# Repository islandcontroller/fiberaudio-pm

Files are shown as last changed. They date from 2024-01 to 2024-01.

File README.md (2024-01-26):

# fiberaudio-pm 

  

A *Pmod&trade; Compatible* peripheral module featuring a pair of active optical audio transmitter/receivers.

<p align="center">
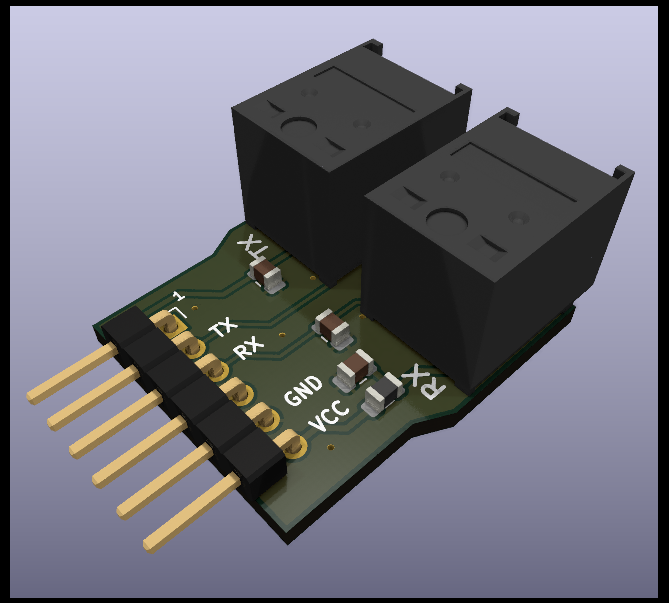
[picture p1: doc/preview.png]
Block schematic
  
</picture></p>

View [**Schematic**](doc/fiberaudio-pm.pdf) &#128196; or [**PCB Preview**](https://htmlpreview.github.io/?https://github.com/islandcontroller/fiberaudio-pm/blob/master/doc/ibom.html) &#127760;.

### Key features

* One pair of active optical audio transmitter/receiver modules (JIS F05, e.g. TOSLINK&trade;)
* One *Digilent Pmod&trade; Compatible* 1x6 pin header
    * Interface Type 1 (GPIO)
* Fully compliant with the [*Digilent Pmod&trade; Interface Specification*, Version 1.3.1](https://digilent.com/reference/_media/reference/pmod/pmod-interface-specification-1_3_1.pdf)

## Overview

The *Pmod&trade; Compatible* fiberaudio-pm peripheral module features a pair of active optical audio transmitter/receiver modules, commonly referred to as "optical S/PDIF". The module allows embedded developers to explore optical data transfer technologies using *Digilent Pmod&trade;* ecosystem components, such as FPGA development boards.

## Review Notes (`Rev.2`)

* CE marking requires compliance with [Directive 2015/863 (EU) amending Annex II to Directive 2011/65/EU](https://eur-lex.europa.eu/legal-content/EN/TXT/?uri=CELEX:32015L0863) (RoHS)
* WEEE marking not required if the board is classified as a 'component' according to [FAQ on Directive 2012/19/EU](https://ec.europa.eu/environment/pdf/waste/weee/faq.pdf) (WEEE)
  * Removed marking in `Rev.3`
* Heat-sinking effect of GND pad thermal spokes is excessive at 400µm width
  * Adjusted to 250µm in `Rev.4`
* "VCC" and "GND" silkscreen placed too close to connector `J1`. Stroke could be a bit wider for better readability.
  * Adjusted position and size in `Rev.4`

## Resources

* [Digilent Pmod&trade; License Agreement](https://digilent.com/reference/_media/pmod/pmod/pmod_license_agreement.pdf)
* Digilent Reference: [Programmable Logic](https://digilent.com/reference/programmable-logic/start)

## Licensing

If not stated otherwise within the specific file, the contents of this project are licensed under the CERN Open Hardware Licence Version 2 - Permissive. The full license text is provided in the [`LICENSE`](LICENSE) document.

    SPDX-License-Identifier: CERN-OHL-P-2.0

This licensing model is compliant with the [Open Source Hardware Definition 1.0](https://www.oshwa.org/definition/).

## Legal Notice

"Digilent" is a registered trademark of *Digilent, Inc*. All other trademarks and registered trademarks mentioned herein are property of their respective owners.

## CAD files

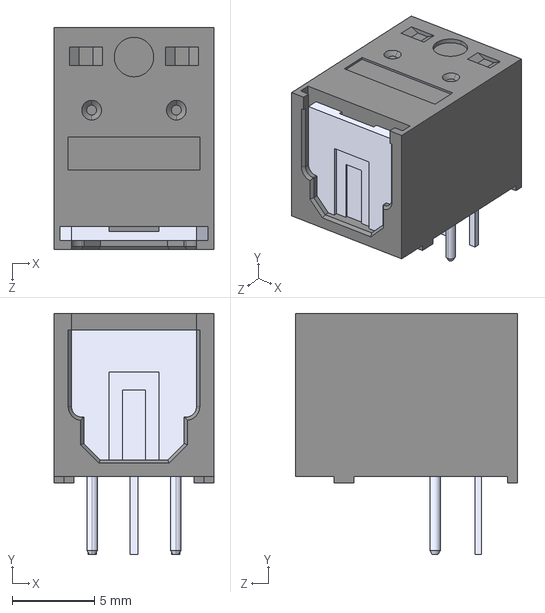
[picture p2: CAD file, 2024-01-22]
doc/everlight_t10w.step
9.70 x 14.7 x 13.5 mm

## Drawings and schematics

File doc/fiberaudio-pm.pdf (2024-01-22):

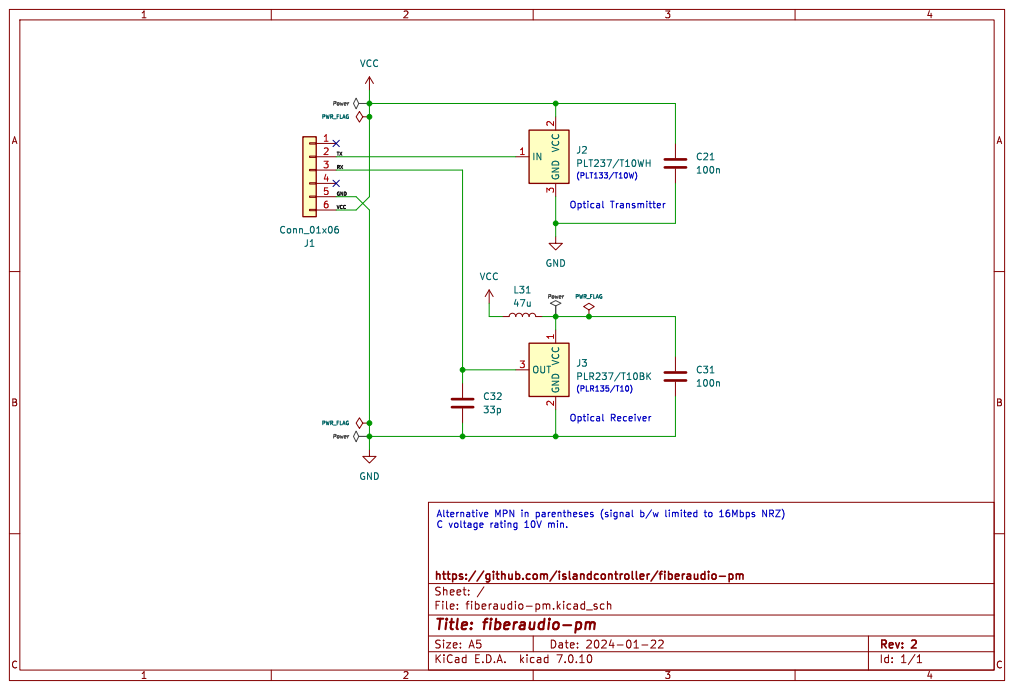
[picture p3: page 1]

File: fiberaudio-pm.kicad_sch Sheet: / https://github.com/islandcontroller/fiberaudio-pm

Id: 1/1 Title: fiberaudio-pm

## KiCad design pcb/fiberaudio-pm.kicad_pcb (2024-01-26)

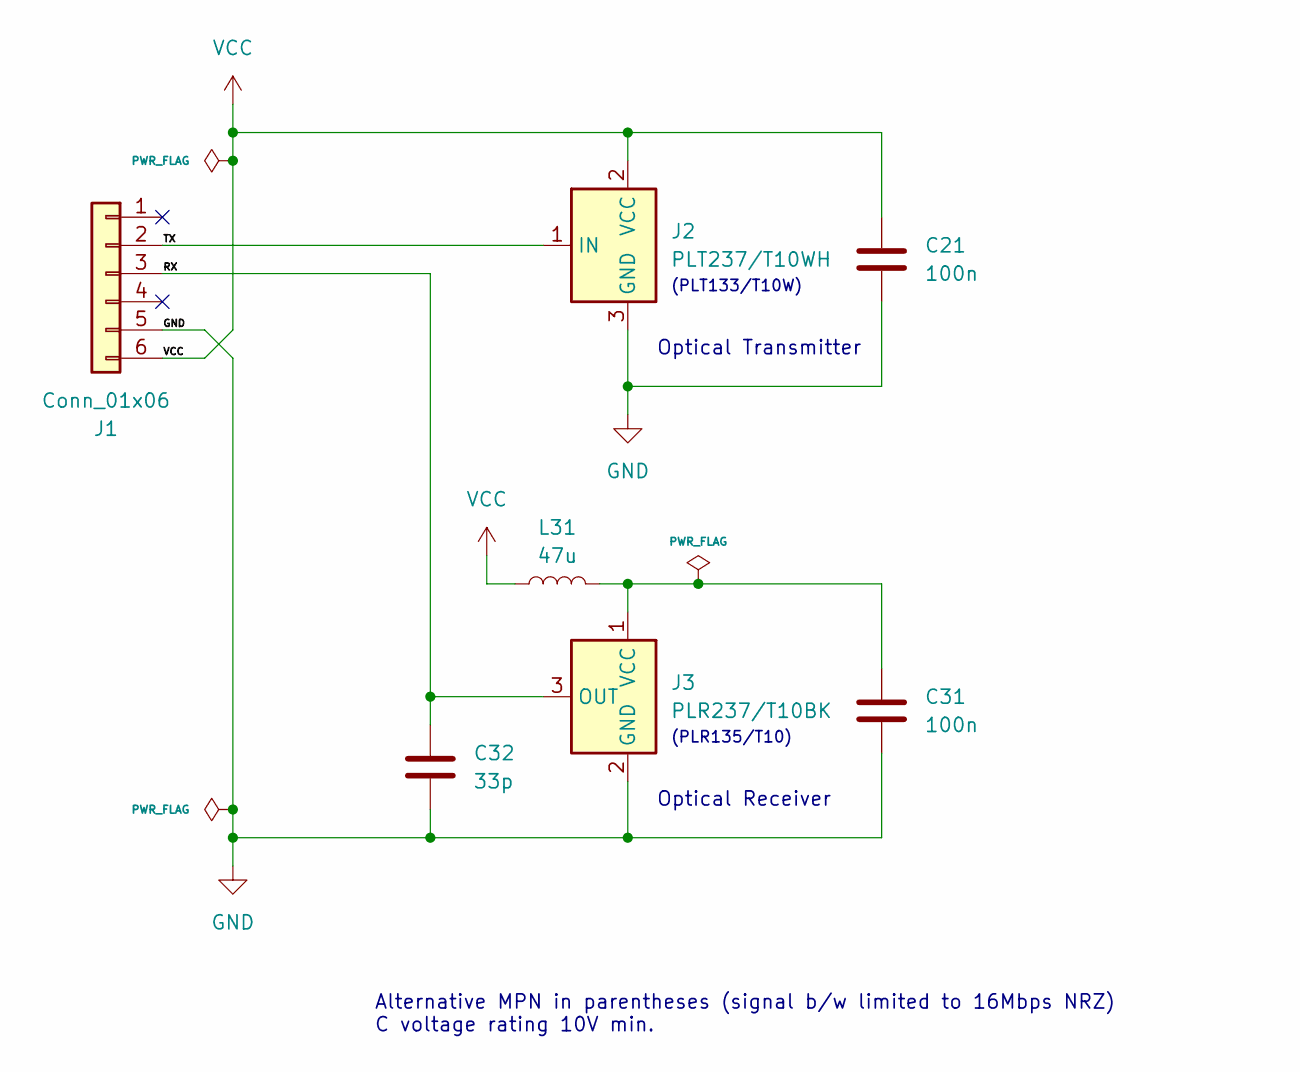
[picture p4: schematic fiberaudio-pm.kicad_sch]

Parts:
C21, C31: 100n; C_0805_2012Metric
C32: 33p; C_0805_2012Metric
J1: Conn_01x06; PinHeader_1x06_P2.54mm_Horizontal_Mirrored
J2: PLT237/T10WH; Connector_T10
J3: PLR237/T10BK; Connector_T10
L31: 47u; L_0805_2012Metric

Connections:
/RX: C32.1, J1.3, J3.3 (OUT)
/TX: J1.2, J2.1 (IN)
GND: C21.2, C31.2, C32.2, J1.5, J2.3 (GND), J3.2 (GND)
unnamed: C31.1, J3.1 (VCC), L31.2
VCC: C21.1, J1.6, J2.2 (VCC), L31.1

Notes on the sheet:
Optical Transmitter
Optical Receiver
Alternative MPN in parentheses (signal b/w limited to 16Mbps NRZ) C voltage rating 10V min.
(PLR135/T10)
(PLT133/T10W)

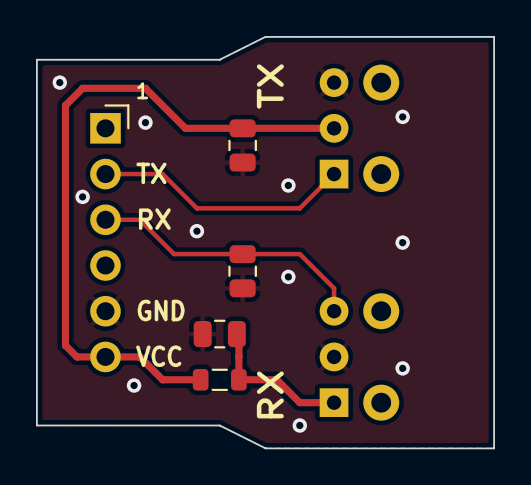
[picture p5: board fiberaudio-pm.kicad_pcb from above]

Board: 2 copper layers, 25.4 x 22.9 mm, 7 parts (0 on the bottom side), 5 nets.

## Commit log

2024-01-22 Added rev.1 schematic and layout; Added license and pcb mfg badges; Updated preview image
    [everlight_t10w.step, fiberaudio-pm.kicad_pcb, fiberaudio-pm.kicad_sch]
2024-01-22 Fixed pin-swap on J3; Updated to Rev.2; Updated documentation
    [fiberaudio-pm.kicad_pcb, fiberaudio-pm.kicad_sch]
2024-01-25 Re-classified as 'component' acc. to FAQ on Directive 2012/19/EU (WEEE2), see http://ec.europa.eu/environment/waste/weee/pdf/faq.pdf; Removed WEEE logo; Added note regarding RoHS compliance requireme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
    [fiberaudio-pm.kicad_pcb]
2024-01-26 Reduced thermal spoke width to 0.25um; Adjusted layout; Adjusted text placement and size
    [fiberaudio-pm.kicad_pcb]
2024-01-26 Updated board preview renderings
2024-01-26 Added review notes for PCB Rev.2

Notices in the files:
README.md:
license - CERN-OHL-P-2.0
